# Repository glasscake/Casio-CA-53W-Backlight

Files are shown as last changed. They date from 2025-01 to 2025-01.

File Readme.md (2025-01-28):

# Casio-CA-53W Backlight Modification PCB

<p float="middle">
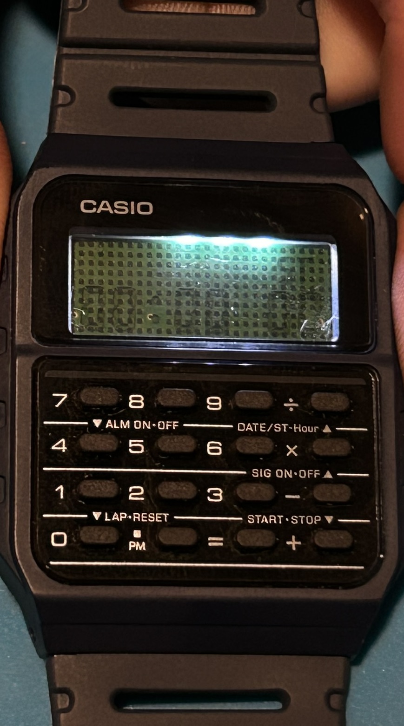
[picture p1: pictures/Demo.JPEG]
  
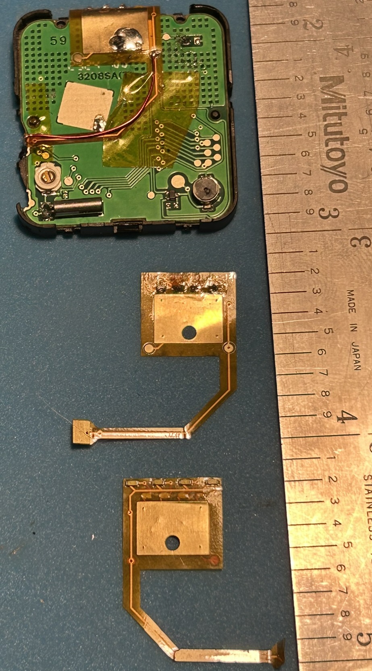
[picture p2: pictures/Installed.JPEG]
  
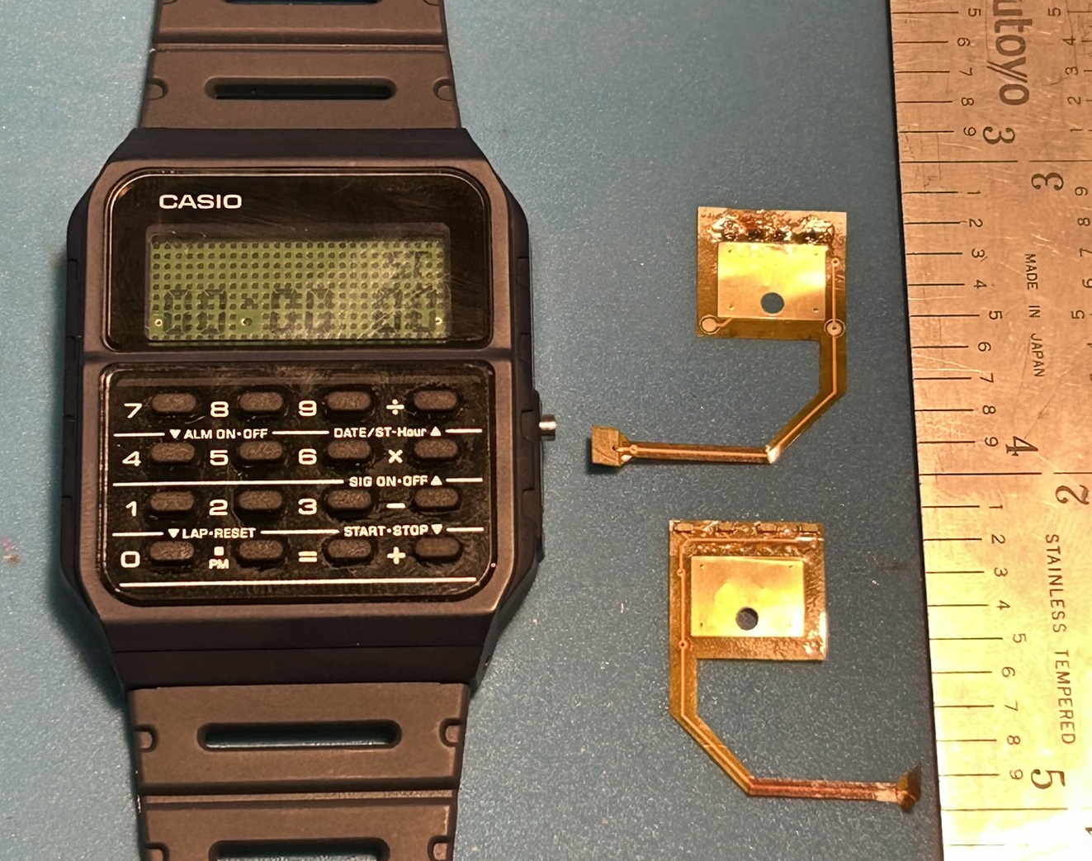
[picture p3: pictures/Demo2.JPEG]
   
</p>

<p float="middle">
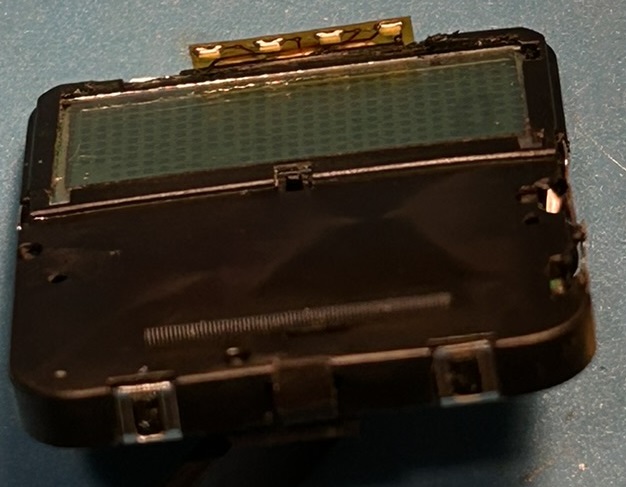
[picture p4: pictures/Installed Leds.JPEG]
  
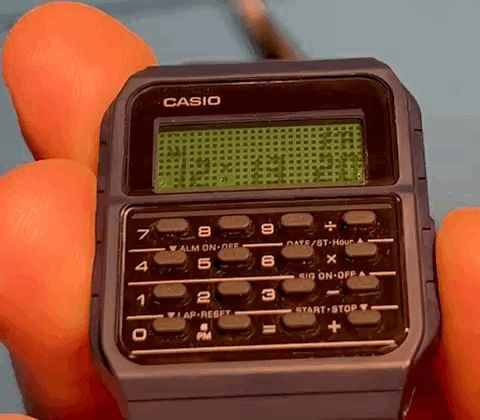
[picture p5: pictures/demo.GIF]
  
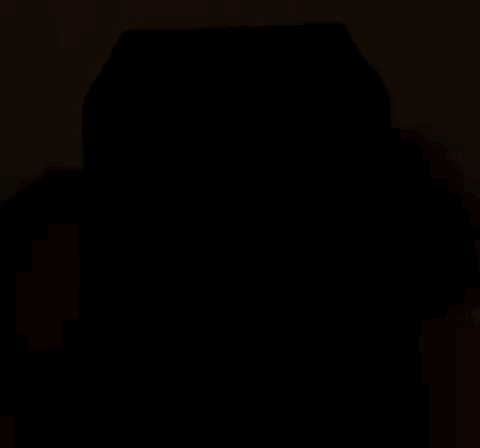
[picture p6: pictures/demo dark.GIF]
  
</p>

## Description
This is a PCB that adds backlight functonality to Casio-CA-53W style watches. It could potentially work with other Casio watches as well.

This project is still very green, a rev A board has been produced and is being tested. significant redesigns are still needed to improve preformance and relability in assembly.
Watch the project and see how development goes.

The design files are made in [KiCad](https://www.kicad.org/) an open source PCB design software.

## Make Your Own
Rev A boards have been produced from JLCPCB; uploading [Rev A.zip](Gerber%20Files/Rev%20A/Rev%20A.zip) to JLCPCB's or other PCB manufacturer's online portal and selecting flex PCB with ENIG sohuld get you boards similar to my own.  
Once a suitable design has been found more thorough ordering instructions will be provided. The current design also has a stiffener, this has no benifit and is not required.

Current limiting resistors can be ommited if diodes with a foward voltage close to 3.0v are carefuly chosen. I am using [Vishay VLMW15 serires](https://www.digikey.com/en/products/detail/vishay-semiconductor-opto-division/VLMW1500-GS08/3504672) 0402(imperial) LEDs at the moment.  
These LEDs have a typical forward voltage of 2.9 volts which means when using the Casio's 3.0v battery the foward current is around 5mA very well within the 20mA rating of the componets. So shunts or solder bridges may be used instead.  
0402 is the smallest componet the average enthusiast will be able to solder by hand so it was chosen for this project.  
the move to 0201(imperial) LEDs may come if 0402 componets are too large to fit and retain splash resistance in the watch.

## Copyright
Copyright 2025 NuE All rights reserved  
Private usage of this project by an individual with no intention to resell or distribute at profit the finished PCB, preassembled PCB, raw PCB, design files, or any item derived from this project is completly allowed.

At the moment this project is not open source. I am trying to figure out a license type that would allow contribution and private use but disallow an individual or company the ability to resell the componets, finished PCB, or design.

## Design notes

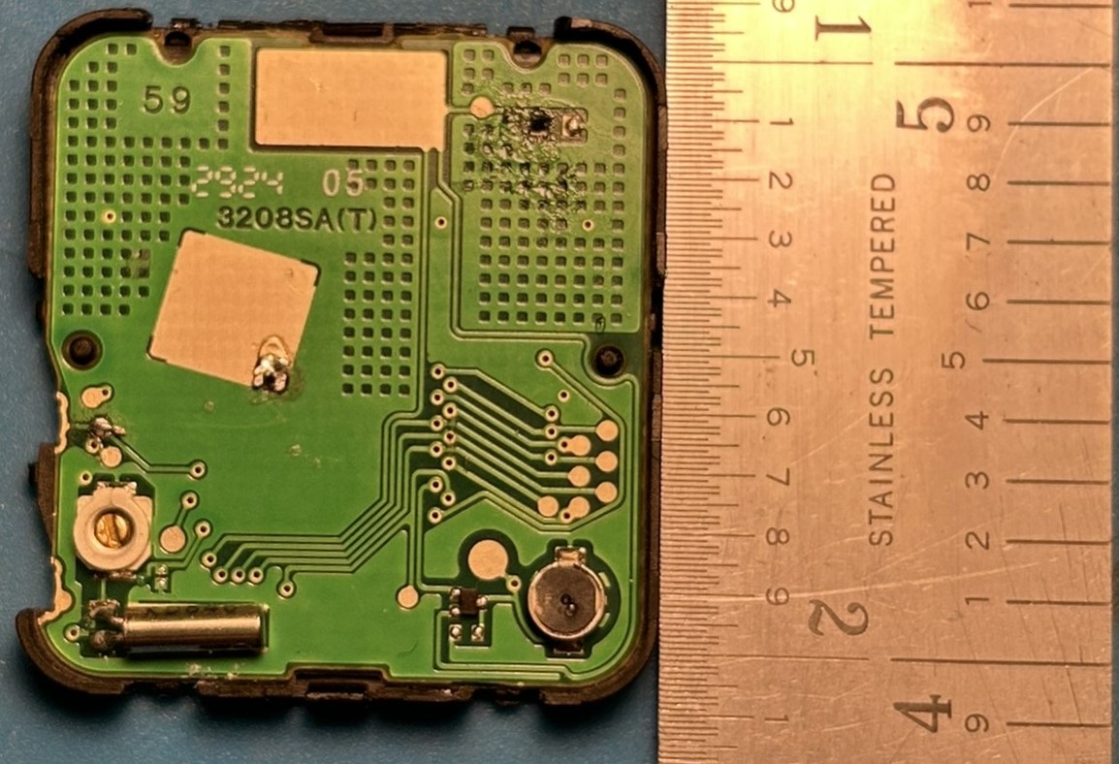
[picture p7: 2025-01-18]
pictures/original pcb.JPEG

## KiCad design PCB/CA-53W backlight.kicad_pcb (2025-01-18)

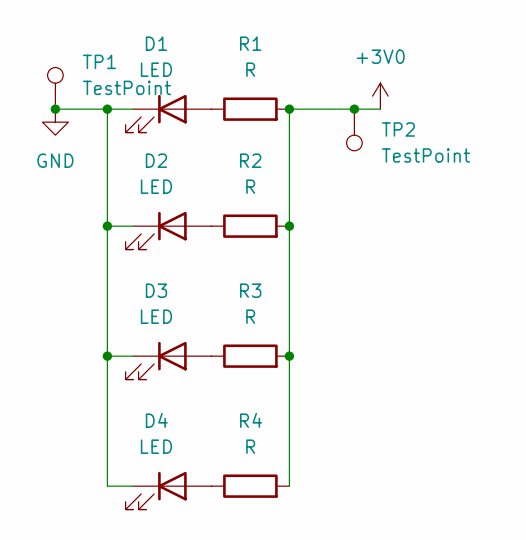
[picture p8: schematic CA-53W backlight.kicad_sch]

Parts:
D1, D2, D3, D4: LED; LED_0402_1005Metric
R1, R2, R3, R4: R; 402 jumper
TP1, TP2: TestPoint; TestPoint_Pad_D1.0mm

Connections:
+3V0: R1.2, R2.2, R3.2, R4.2, TP2.1
GND: D1.1 (K), D2.1 (K), D3.1 (K), D4.1 (K), TP1.1
unnamed: D1.2 (A), R1.1
unnamed: D2.2 (A), R2.1
unnamed: D3.2 (A), R3.1
unnamed: D4.2 (A), R4.1

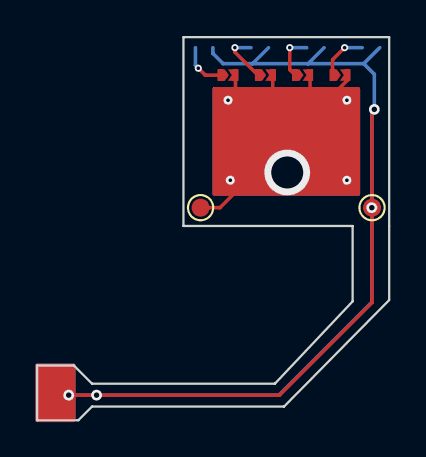
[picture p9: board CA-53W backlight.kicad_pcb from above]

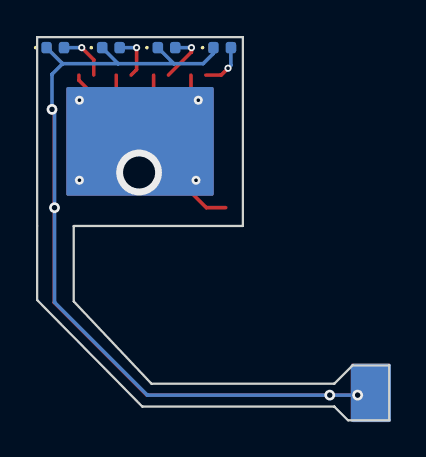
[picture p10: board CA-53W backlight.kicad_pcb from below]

Board: 2 copper layers, 19.6 x 21.3 mm, 10 parts (4 on the bottom side), 6 nets.

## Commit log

2025-01-17 Inital
    PCB Layout, basic components, pads and test points
    [CA-53W backlight.kicad_pcb, CA-53W backlight.kicad_sch]
2025-01-18 image and press button layout
    adding image for ref and starting to lay out press button
    [CA-53W backlight.kicad_pcb]
2025-01-18 Out for boards Rev A
    getting quoted through JLC PCB
    [CA-53W backlight-B_Cu.gbl, CA-53W backlight-B_Mask.gbs, CA-53W backlight-B_Paste.gbp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]
2025-01-20 Cleanup and rename
    Cleaning up directories and renaming
    [CA-53W backlight-B_Cu.gbl, CA-53W backlight-B_Mask.gbs, CA-53W backlight-B_Paste.gbp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]
